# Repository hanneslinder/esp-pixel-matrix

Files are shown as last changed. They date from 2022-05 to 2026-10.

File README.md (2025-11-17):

# ESP-32 Pixel Matrix









## Setup

### web app

- install dependencies with `npm i`
- rename `config.example.ts` file to `config.ts`
- `npm run debug` for local development
- For local development: Update esp32 IP adress in `webpack.config.dev.js`
- `npm run build` to build the project

You should now be able to navigate to `localhost:8080` in your browser. If the ESP32 is already setup and running you should be able to control the matrix now.

### ESP-32

The esp32 code uses [platformIO](https://platformio.org/)

- install dependencies
- wire up the esp
- take contents of `browser/dist` folder and copy into `esp32/data` directory.
- copy data onto esp32 via platformIO `build file system image` and `upload file system image`.

When power is connected, the ESP32 creates a WIFI hotspot and displays the connection settings on the matrix. Connect to this network and use the WIFI portal to configure your WIFI settings. [The credentials for connecting to the portal can be found here](https://github.com/hanneslinder/esp-pixel-matrix/blob/main/esp32/src/main.cpp#L55) The ESP32 then reboots and trys to connect to the configured WIFI. On subsequent reboots, the matrix will show its IP address for 10 seconds before switching to its regular mode.

### OTA updates

Once the matrix is up and running you can update the web app and the ESP32 code via OTA updates.
In the `settings` section of the web interface there is an upload form for OTA update data. This form expects 2 files to be uploaded:
`spiffs.bin` and `firmware.bin`

`spiffs.bin`: contains the web app and can be build via platformIO -> `Build File System Image`
(The web app build process should already copy the built artifacts to the `/esp32/data` directory, which is then used for building the file system image)

`firmware.bin`: contains the esp32 code and can be build via platformIO -> `Build`

The output of both commands sould be located in the `.pio/build/wemos_d1_mini32` folder (`wemos_d1_mini32` might be different if you use another device as build target)

Just upload both files in the web UI. After successful upload the device reboots itself and should have the new code. In theory there should be a rollback mechanism for botched updates included but I've not tried this. So best to not unplug the power while flashing a new firmware :)

Please note that your ESP32 needs the `ota.csv` partition layout!

### pre-build files

In the `bin` directory you can find a pre-build firmware and file system image, suitable for `esp32doit-devkit-v1`. Please note that these files probably won't work with other esp32 boards! If you have another board and cannot build these files yourself, please open an issue and I will add them!

### wire up

This project uses the excellent https://github.com/mrfaptastic/ESP32-HUB75-MatrixPanel-I2S-DMA library. If you are unsure how to connect, there is a nice connection guide there.
In short:

```
  HUB 75 PANEL         ESP 32 PIN
+----------+
|  R1  G1  |    R1  -> IO25    G1 -> IO26
|  B1  GND |    B1  -> IO27
|  R2  G2  |    R2  -> IO14    G2 -> IO12
|  B2  E   |    B2  -> IO13     E -> N/A (required for 1/32 scan panels, like 64x64. Any available pin would do, i.e. IO32 )
|   A  B   |    A   -> IO23     B -> IO19
|   C  D   |    C   -> IO05     D -> IO17
| CLK  LAT |    CLK -> IO16   LAT -> IO 4
|  OE  GND |    OE  -> IO15   GND -> ESP32 GND
+----------+
```

There is also a Gerber file located in the `hardware` folder for a PCB to simplify the connection.

### print the case

You can find `STL` and `STEP` files for the case inside the `hardware` folder.
The case should fit a standard 64x32 pixel p3 led matrix.
I've designed the case to use M3 threaded inserts for all screw holes.
For power I've used a micro usb breakout board like this one: https://www.amazon.de/WayinTop-Breakout-Konverter-Netzteil-Steckbrett/dp/B07W13X3TD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

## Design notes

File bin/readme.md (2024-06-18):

This directory contains pre-build binaries for the `esp32 doit devkit v1` board. (That's what I use for this project)

`firmware.bin` is the esp32 code

`spiffs.bin` contains the file system image that includes the browser based react application

`partitions.bin` contains partition table information

Please be aware that you need to flash all files!

Once you have flashed the files, you should be able to access the captive portal and use it to connect to your wifi.

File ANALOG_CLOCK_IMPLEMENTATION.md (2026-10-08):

# Analog Clock Face Implementation Plan

**Date:** November 17, 2025  
**Status:** Planning Phase - Ready to Implement

## Overview

Implementation of an analog clock face feature for the 64x32 pixel LED matrix display. The clock will be rendered autonomously by the ESP32 and configured via the web UI.

## Design Decisions

### Architecture Pattern

Follows the existing `TextDisplayHandler` pattern:

- **ESP32**: Autonomously renders clock every second using system time
- **Web UI**: Sends configuration once, then provides preview
- **No repeated WebSocket messages** - ESP32 handles all rendering independently

### Feasibility Analysis

A 64x32 pixel display can show a readable analog clock:

- **Clock diameter**: ~28-30 pixels (fits within 32px height)
- **Horizontal centering**: ~17px margins on 64px width
- **Hand design**: Thick hands (2-3px) with different lengths and colors
- **Hour markers**: 12 dots or cardinal points (3, 6, 9, 12)

Similar to classic LCD watch faces that were 20-30 pixels and perfectly readable.

## Implementation Plan

### 1. Add Clock Configuration Types

#### Frontend: `browser/src/state/appState.ts`

```typescript
export interface ClockConfig {
  enabled: boolean;
  centerX: number;          // X position of clock center (0-63)
  centerY: number;          // Y position of clock center (0-31)
  radius: number;           // Clock face radius in pixels
  hourHandColor: string;    // Hex color for hour hand
  minuteHandColor: string;  // Hex color for minute hand
  secondHandColor: string;  // Hex color for second hand
  showSecondHand: boolean;  // Toggle second hand visibility
  hourMarkers: boolean;     // Show hour marker dots
  showBorder: boolean;      // Show clock circle border
  borderColor: string;      // Hex color for border
  hourHandLength: number;   // Length multiplier (0.0-1.0)
  minuteHandLength: number; // Length multiplier (0.0-1.0)
  secondHandLength: number; // Length multiplier (0.0-1.0)
  hourHandWidth: number;    // Hand thickness in pixels
  minuteHandWidth: number;  // Hand thickness in pixels
  secondHandWidth: number;  // Hand thickness in pixels
}

// Add to AppState interface
export interface AppState {
  // ... existing fields ...
  clock: ClockConfig;
}

// Add to getInitialState()
clock: {
  enabled: false,
  centerX: 32,
  centerY: 16,
  radius: 14,
  hourHandColor: "#ffffff",
  minuteHandColor: "#00aaff",
  secondHandColor: "#ff0000",
  showSecondHand: true,
  hourMarkers: true,
  showBorder: true,
  borderColor: "#ffffff",
  hourHandLength: 0.5,
  minuteHandLength: 0.8,
  secondHandLength: 0.9,
  hourHandWidth: 2,
  minuteHandWidth: 2,
  secondHandWidth: 1,
}
```

#### Backend: `esp32/src/types/CommonTypes.h`

```cpp
struct ClockConfig {
  bool enabled;
  int8_t centerX;
  int8_t centerY;
  uint8_t radius;
  uint16_t hourHandColor;     // 565 RGB color
  uint16_t minuteHandColor;   // 565 RGB color
  uint16_t secondHandColor;   // 565 RGB color
  bool showSecondHand;
  bool hourMarkers;
  bool showBorder;
  uint16_t borderColor;
  float hourHandLength;       // 0.0-1.0 multiplier
  float minuteHandLength;     // 0.0-1.0 multiplier
  float secondHandLength;     // 0.0-1.0 multiplier
  uint8_t hourHandWidth;
  uint8_t minuteHandWidth;
  uint8_t secondHandWidth;
};
```

### 2. Create ESP32 ClockDisplayHandler

#### `esp32/src/display/ClockDisplayHandler.h`

```cpp
#ifndef CLOCK_DISPLAY_HANDLER_H
#define CLOCK_DISPLAY_HANDLER_H

#include <Arduino.h>
#include <time.h>
#include "../matrix/MatrixController.h"
#include "../types/CommonTypes.h"

class ClockDisplayHandler {
public:
  ClockDisplayHandler(MatrixController& matrix, ClockConfig* config);

  void renderClock();
  ClockConfig* getConfig();

private:
  void drawClockFace();
  void drawHourMarkers();
  void drawClockHands(int hour, int minute, int second);
  void drawHand(float angle, float length, uint16_t color, uint8_t width);

  MatrixController& _matrix;
  ClockConfig* _config;
  time_t _lastUpdateTime;
};

#endif // CLOCK_DISPLAY_HANDLER_H
```

#### `esp32/src/display/ClockDisplayHandler.cpp`

Key implementation points:

- Get current time using `getLocalTime()`
- Calculate hand angles:
  - Hour: `(hour % 12) * 30 + (minute * 0.5)` degrees
  - Minute: `minute * 6` degrees
  - Second: `second * 6` degrees
- Convert degrees to radians and calculate endpoints
- Use `matrix.drawLine()` for hands
- Use `matrix.drawCircle()` for border
- Use `matrix.fillCircle()` for hour markers
- Only update once per second (check `time_t` change)

### 3. Add WebSocket Handler for Clock Config

#### `esp32/src/websocket/WebSocketHandler.cpp`

Add `handleSetClock()` function:

```cpp
void handleSetClock(JsonDocument& doc) {
  JsonObject clockObj = doc["clock"].as<JsonObject>();

  clockConfig.enabled = clockObj["enabled"];
  clockConfig.centerX = clockObj["centerX"];
  clockConfig.centerY = clockObj["centerY"];
  clockConfig.radius = clockObj["radius"];
  clockConfig.hourHandColor = strtol(clockObj["hourHandColor"], NULL, 16);
  clockConfig.minuteHandColor = strtol(clockObj["minuteHandColor"], NULL, 16);
  clockConfig.secondHandColor = strtol(clockObj["secondHandColor"], NULL, 16);
  clockConfig.showSecondHand = clockObj["showSecondHand"];
  clockConfig.hourMarkers = clockObj["hourMarkers"];
  clockConfig.showBorder = clockObj["showBorder"];
  clockConfig.borderColor = strtol(clockObj["borderColor"], NULL, 16);
  clockConfig.hourHandLength = clockObj["hourHandLength"];
  clockConfig.minuteHandLength = clockObj["minuteHandLength"];
  clockConfig.secondHandLength = clockObj["secondHandLength"];
  clockConfig.hourHandWidth = clockObj["hourHandWidth"];
  clockConfig.minuteHandWidth = clockObj["minuteHandWidth"];
  clockConfig.secondHandWidth = clockObj["secondHandWidth"];
}
```

Register in `handleMessage()`:

```cpp
} else if (isStringEqual(action, "setClock")) {
  handleSetClock(doc);
}
```

### 4. Integrate Clock Rendering in Main Loop

#### `esp32/src/main.cpp`

```cpp
// Add global
ClockConfig clockConfig = {
  .enabled = false,
  .centerX = 32,
  .centerY = 16,
  .radius = 14,
  // ... other defaults
};

// Initialize in setup()
ClockDisplayHandler clockDisplay(matrix, &clockConfig);

// In loop(), add after text rendering:
} else if (clockConfig.enabled) {
  clockDisplay.renderClock();
}
```

### 5. Create Browser Canvas Clock Preview Layer

#### `browser/src/components/canvas/CanvasClockLayer.ts`

```typescript
import { observe } from "@nx-js/observer-util";
import { appState } from "../../state/appState";

export class CanvasClockLayer {
  private ctx: CanvasRenderingContext2D;
  private canvas: HTMLCanvasElement;
  private updateInterval: any;

  constructor(container: HTMLElement) {
    this.canvas = document.createElement("canvas");
    this.canvas.setAttribute("id", "canvas-clock-layer");
    this.ctx = this.canvas.getContext("2d");

    this.canvas.width = appState.settings.width * appState.settings.pixelRatio;
    this.canvas.height =
      appState.settings.height * appState.settings.pixelRatio;

    container.appendChild(this.canvas);
    this.observeChanges();
  }

  private observeChanges() {
    observe(() => {
      if (appState.clock.enabled) {
        this.startClock();
      } else {
        this.stopClock();
      }
    });
  }

  private startClock() {
    clearInterval(this.updateInterval);
    this.updateInterval = setInterval(() => this.renderClock(), 1000);
    this.renderClock(); // Immediate render
  }

  private stopClock() {
    clearInterval(this.updateInterval);
    this.reset();
  }

  private renderClock() {
    const config = appState.clock;
    const ratio = appState.settings.pixelRatio;
    const now = new Date();

    this.reset();

    if (!config.enabled) return;

    const centerX = config.centerX * ratio;
    const centerY = config.centerY * ratio;
    const radius = config.radius * ratio;

    // Draw border
    if (config.showBorder) {
      this.ctx.strokeStyle = config.borderColor;
      this.ctx.lineWidth = ratio;
      this.ctx.beginPath();
      this.ctx.arc(centerX, centerY, radius, 0, 2 * Math.PI);
      this.ctx.stroke();
    }

    // Draw hour markers
    if (config.hourMarkers) {
      for (let i = 0; i < 12; i++) {
        const angle = ((i * 30 - 90) * Math.PI) / 180;
        const markerRadius = radius * 0.85;
        const x = centerX + Math.cos(angle) * markerRadius;
        const y = centerY + Math.sin(angle) * markerRadius;

        this.ctx.fillStyle = config.borderColor;
        this.ctx.beginPath();
        this.ctx.arc(x, y, ratio, 0, 2 * Math.PI);
        this.ctx.fill();
      }
    }

    // Calculate angles
    const hours = now.getHours() % 12;
    const minutes = now.getMinutes();
    const seconds = now.getSeconds();

    const hourAngle = ((hours * 30 + minutes * 0.5 - 90) * Math.PI) / 180;
    const minuteAngle = ((minutes * 6 - 90) * Math.PI) / 180;
    const secondAngle = ((seconds * 6 - 90) * Math.PI) / 180;

    // Draw hands
    this.drawHand(
      centerX,
      centerY,
      hourAngle,
      radius * config.hourHandLength,
      config.hourHandColor,
      config.hourHandWidth * ratio
    );
    this.drawHand(
      centerX,
      centerY,
      minuteAngle,
      radius * config.minuteHandLength,
      config.minuteHandColor,
      config.minuteHandWidth * ratio
    );
    if (config.showSecondHand) {
      this.drawHand(
        centerX,
        centerY,
        secondAngle,
        radius * config.secondHandLength,
        config.secondHandColor,
        config.secondHandWidth * ratio
      );
    }
  }

  private drawHand(
    cx: number,
    cy: number,
    angle: number,
    length: number,
    color: string,
    width: number
  ) {
    this.ctx.strokeStyle = color;
    this.ctx.lineWidth = width;
    this.ctx.lineCap = "round";
    this.ctx.beginPath();
    this.ctx.moveTo(cx, cy);
    this.ctx.lineTo(
      cx + Math.cos(angle) * length,
      cy + Math.sin(angle) * length
    );
    this.ctx.stroke();
  }

  private reset() {
    this.ctx.clearRect(0, 0, this.canvas.width, this.canvas.height);
  }

  public destroy() {
    clearInterval(this.updateInterval);
    this.canvas.remove();
  }
}
```

### 6. Create Clock View Component

#### `browser/src/components/views/clock/ClockView.tsx`

UI controls needed:

- Toggle clock enabled
- Color pickers for each hand and border
- Sliders for position (centerX, centerY)
- Slider for radius
- Sliders for hand lengths
- Sliders for hand widths
- Toggles for second hand, hour markers, border

### 7. Add Clock Action and Integration

#### `browser/src/Actions.ts`

```typescript
export const setClockAction = () => {
  const clockToSend = {
    ...appState.clock,
    hourHandColor: convertHexTo16Bit(appState.clock.hourHandColor),
    minuteHandColor: convertHexTo16Bit(appState.clock.minuteHandColor),
    secondHandColor: convertHexTo16Bit(appState.clock.secondHandColor),
    borderColor: convertHexTo16Bit(appState.clock.borderColor),
  };

  const msg = {
    action: "setClock",
    clock: clockToSend,
  };

  socket.send(msg);
};
```

#### `browser/src/components/Navigation.tsx`

Add Clock to Views enum and navigation items

#### `browser/src/components/canvas/CanvasWrapper.tsx`

Instantiate CanvasClockLayer alongside other layers

## Technical Notes

### Math for Clock Hands

```
Hour Hand Angle = (hours % 12) * 30 + (minutes * 0.5) - 90 degrees
Minute Hand Angle = minutes * 6 - 90 degrees
Second Hand Angle = seconds * 6 - 90 degrees

// Convert to radians and calculate endpoint:
x = centerX + cos(angle * PI / 180) * length
y = centerY + sin(angle * PI / 180) * length
```

### ESP32 Drawing Functions Available

- `matrix->drawLine(x0, y0, x1, y1, color)`
- `matrix->drawCircle(x, y, radius, color)`
- `matrix->fillCircle(x, y, radius, color)`
- `matrix->drawPixel(x, y, color)`

### Performance Considerations

- ESP32 should only redraw when second changes (check `time_t`)
- Browser can update every second with `setInterval`
- Use separate layer to avoid redrawing background
- Consider clearing only clock layer, not entire display

## Testing Checklist

- [ ] Clock configuration saves/loads properly
- [ ] Clock hands move correctly (test at different times)
- [ ] Browser preview matches ESP32 display
- [ ] Second hand toggle works
- [ ] Hour markers toggle works
- [ ] All color pickers work
- [ ] Clock can be positioned anywhere on display
- [ ] Clock resizes correctly with radius slider
- [ ] Hand lengths and widths adjust properly
- [ ] Clock disables properly when toggled off
- [ ] Clock works with different composition modes
- [ ] Clock coexists with text/background layers

## Future Enhancements (Optional)

- Multiple clock face styles (Roman numerals, digital hybrid, etc.)
- Date display inside/below clock
- Timezone selection per clock
- Multiple clocks showing different timezones
- Smooth second hand motion (interpolation)
- Custom color schemes / presets
- Day/night mode auto-brightness

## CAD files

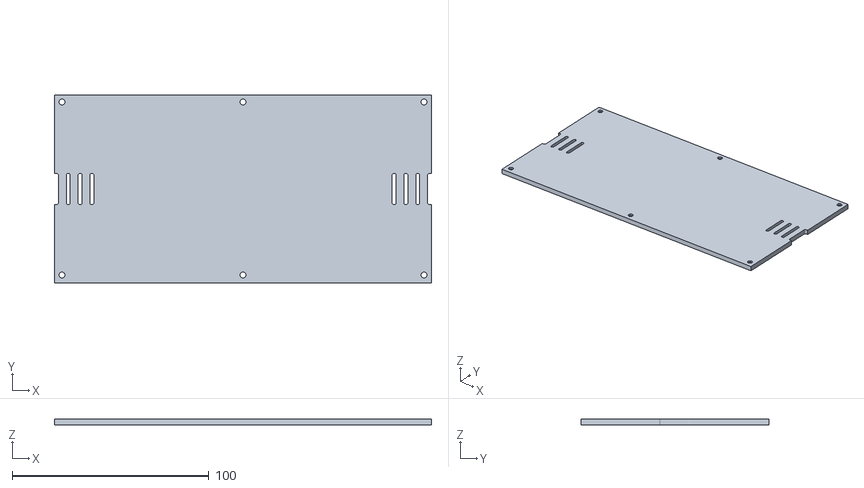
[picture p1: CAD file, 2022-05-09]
hardware/matrix-case-back.stl
191.6 x 95.6 x 3.00

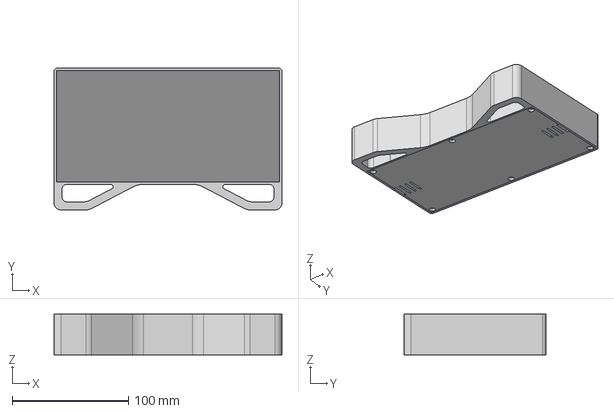
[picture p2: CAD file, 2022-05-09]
hardware/matrix-case.step
196.0 x 122.0 x 35.0 mm

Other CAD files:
hardware/matrix-case.stl

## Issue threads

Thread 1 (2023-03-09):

Please consider uploading the PCB schematics

manutenfruits, 2023-03-09:
Hi, I got your pcb fabricated but I'm missing some information like schematics, and what component goes in the small square (I'm guessing a photoresistor?).

I know I can reverse engineer it but would be great if we had access to the original schematic, or even better, the whole kicad project (if you used that!).

Thanks!

hanneslinder, 2023-05-09:
Sorry for the late reply, completely missed your comment.
Regarding the schematic, I created it with [EasyEDA](https://easyeda.com/), so there is no kicad file I can share.

Now that you point it out I never specified what the additional through holes are for 🙈
The larger one is for providing power and the smaller one is for a push button that resets the clock when pressed for 5 seconds.

I've attached a picture of the backside of the clock, hope that clears it up a bit
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

Let me know if you have any more questions.
Cheers!

Closed 2023-09-12.

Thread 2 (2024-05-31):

Informations ?

spordiab, 2024-05-31:
Thank you for your project, however I don't have much programming knowledge, I use Arduino IDE and I have the same ESP32 board with the same Matrix screen.  I wanted to know if you could generate a.bin file to flash directly with ESPHome Flasher, it would be easier for beginners.  Thank you so much

hanneslinder, 2024-06-17:
Thanks for the suggestion and sorry for my late reply.
A `.bin` file sounds like an interesting addition to help getting started with the project faster. I'll look into it and add it to the project as soon as I find the time 👍

hanneslinder, 2024-06-17:
@spordiab I've added pre-build files for the `esp32doit-devkit-v1` board in the `/bin` directory. Please note that you also need to flash both files!
Let me know if this works for you.

cheers!

spordiab, 2024-06-17:
OMG, Thanks 😊

Closed 2024-06-17.

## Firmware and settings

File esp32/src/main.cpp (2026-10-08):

#include "SPIFFS.h"
#include "time.h"
#include <Arduino.h>
#include <ArduinoJson.h>
#include <AsyncTCP.h>
#include <ESP32-HUB75-MatrixPanel-I2S-DMA.h>
#include <ESPAsyncWebServer.h>
#include <ESPmDNS.h>
#include <Fonts/Picopixel.h>
#include <GFX_Layer.hpp>
#include <HTTPClient.h>
#include <MycilaESPConnect.h>
#include <Update.h>
#include <WiFi.h>
#include <Wire.h>
#include <sstream>

#include "config/ConfigManager.h"
#include "config/pins.h"
#include "config/secrets.h"
#include "config/settings.h"
#include "data/CustomDataHandler.h"
#include "display/TextDisplayHandler.h"
#include "input/ResetButtonHandler.h"
#include "matrix/MatrixController.h"
#include "ota/OTAUpdateHandler.h"
#include "quiet/QuietHoursHandler.h"
#include "server/WebServerHandler.h"
#include "types/CommonTypes.h"
#include "utils/utils.h"
#include "websocket/WebSocketHandler.h"
#include "wifi/WiFiConnectionHandler.h"

#define U_PART U_SPIFFS

// Get singleton instance of ConfigManager
ConfigManager& config = ConfigManager::getInstance();

// Moved OTA progress state into OTAUpdate module

MatrixController matrix;

bool startupFinished = false;

// clock options - to be migrated to state manager
boolean showText = true;
boolean lastshowText = false;
boolean forceUpdateTime = false;

// Mutable copies for runtime configuration
char currentTimezone[64];

TextItem textContent[5]
    = { { "%H:%M", 0xFFFF, -1, -5, 1, 2, 1 }, { "%d.%b", 0xFFFF, 2, -3, 1, 1, 2 } };

char* socketData;
int currSocketBufferIndex = 0;

// custom data - kept for WebSocketHandler access
int customDataUpdateInterval = -1;
boolean customDataEnabled = false;
char customDataServer[128] = "";

static unsigned long lastHeapCheck = 0;
static size_t minFreeHeap = SIZE_MAX;

// Initialize handlers and server
AsyncWebServer server(80);
AsyncWebSocket ws("/ws");
WiFiConnectionHandler wifiHandler(server);
ResetButtonHandler resetButton(RESET_PIN, RESET_SHORT_PRESS_TIME);
TextDisplayHandler textDisplay(matrix, textContent, 5);
QuietHoursHandler quietHours(matrix);
WebServerHandler webServer(server, ws);
CustomDataHandler customData;

void initMatrix() { matrix.begin(); }

void onEvent(AsyncWebSocket* server, AsyncWebSocketClient* client, AwsEventType type, void* arg,
    uint8_t* data, size_t len)
{
  switch (type) {
  case WS_EVT_CONNECT:
    WebSocketHandler::onConnect(client);
    break;
  case WS_EVT_DISCONNECT:
    WebSocketHandler::onDisconnect(client);
    break;
  case WS_EVT_DATA:
    WebSocketHandler::handleMessage(arg, data, len);
    break;
  case WS_EVT_PONG:
    break;
  case WS_EVT_ERROR:
    WebSocketHandler::onError(client);
    break;
  }
}

void resetWifi() { wifiHandler.reset(); }

void initWebSocket()
{
  ws.onEvent(onEvent);
  server.addHandler(&ws);
  ws.enable(true);

  WebSocketHandler::init(&matrix, textContent, &ws, socketData, &currSocketBufferIndex,
      SOCKET_DATA_SIZE, &textDisplay, &customData, &quietHours);
}

void checkHeapAndLog()
{
  size_t freeHeap = ESP.getFreeHeap();
  size_t heapSize = ESP.getHeapSize();
  size_t minHeap = ESP.getMinFreeHeap();

  if (freeHeap < minFreeHeap) {
    minFreeHeap = freeHeap;
  }

  Serial.println("=== System Status ===");
  Serial.printf("Free Heap: %u bytes (%.1f%%)\n", freeHeap, (freeHeap * 100.0) / heapSize);
  Serial.printf("Min Free Heap: %u bytes\n", minHeap);
  Serial.printf("Heap Size: %u bytes\n", heapSize);
  Serial.printf("WiFi Status: %s (RSSI: %d dBm)\n",
      wifiHandler.isConnected() ? "Connected" : "Disconnected", wifiHandler.getRSSI());
  Serial.printf("WebSocket Clients: %u\n", ws.count());
  Serial.printf("Uptime: %lu seconds\n", millis() / 1000);
  Serial.println("====================");

  // Warning if heap is getting low
  if (freeHeap < 30000) {
    Serial.println("WARNING: Low heap memory! System may become unstable.");
  }
}

void setup()
{
  Serial.begin(115200);
  SPIFFS.begin();

  // Initialize ConfigManager first
  config.begin();

  // Initialize text display with locale from config
  textDisplay.setLocale(config.getLocale());

  socketData = (char*)malloc(SOCKET_DATA_SIZE * sizeof(char));

  // Initialize reset button
  resetButton.begin();
  resetButton.onLongPress([]() { resetWifi(); });

  // Copy timezone from config for runtime use
  strlcpy(currentTimezone, config.getTimezone(), sizeof(currentTimezone));

  // Initialize WiFi
  wifiHandler.begin(useCaptivePortal, ssid, password);

  // Initialize matrix
  initMatrix();

  // Apply brightness from config
  matrix.setBrightness(config.getBrightness());
  Serial.printf("Set initial brightness to %d\n", config.getBrightness());

  // Quiet hours need the matrix ready before they can take over the screen
  quietHours.begin();

  // Initialize WebSocket and Web Server
  initWebSocket();
  webServer.begin();

  // Configure timezone and NTP
  configTzTime(config.getTimezone(), config.getNtpServer());
  Serial.printf("Configured NTP: %s, Timezone: %s\n", config.getNtpServer(), config.getTimezone());
}

void loop()
{
  wifiHandler.loop();
  resetButton.update();

  if (startupFinished == false) {
    const String ip = wifiHandler.getIPAddress();

    matrix.drawText(ip.c_str(), MIDDLE, &Picopixel, 0xFFFF, 1, 0, 0, 1);
    matrix.render(config.getCompositionMode());

    delay(6000);

    startupFinished = true;
  } else if (resetButton.isPressed()) {
    char resetTimeString[16];
    itoa(resetButton.getPressDuration(), resetTimeString, 10);
    matrix.getTextLayer().clear();
    matrix.getTextLayer().setCursor(0, 0);
    matrix.getTextLayer().println("Reset");
    matrix.getTextLayer().setCursor(0, 16);
    matrix.getTextLayer().println(resetTimeString);
  } else if (showText == true) {
    textDisplay.renderText();
  }

  customData.update();

  ws.cleanupClients();

  // Quiet hours take over the screen when they are active, so this decides
  // what the panel shows before the frame is pushed out.
  quietHours.update();

  matrix.render(config.getCompositionMode(), quietHours.isActive());

  if (millis() - lastHeapCheck > 300000) {
    lastHeapCheck = millis();
    checkHeapAndLog();
  }

  wifiHandler.checkConnection();

  delay(100);
}

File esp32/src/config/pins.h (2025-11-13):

#pragma once

// Matrix Panel Pins
#define USE_CUSTOM_PINS
#define A_PIN 5
#define B_PIN 19
#define C_PIN 22
#define D_PIN 21
#define E_PIN 12

#define R1_PIN 2
#define R2_PIN 18
#define G1_PIN 15
#define G2_PIN 27
#define B1_PIN 4
#define B2_PIN 14

#define CLK_PIN 23
#define LAT_PIN 25
#define OE_PIN 26

#define RESET_PIN 32

// Matrix Configuration
#define PANEL_WIDTH 64
#define PANEL_HEIGHT 32
#define PANEL_CHAIN 1

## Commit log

2022-05-09 open source repo
    [matrix-case-back.stl, matrix-case.step, matrix-case.stl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]
2022-05-10 Fix syncing of empty text lines
    [main.cpp]
2022-05-16 Fix text restore bug. Introduct experimental new text renderer.
    [main.cpp]
2022-05-17 Increase SPIFFS partition size
    [ota.csv]
2023-12-27 Fix wifi sleep and add formatter
    [main.cpp]
2024-06-17 Add pre-build files for `esp32doit-devkit-v1`
2025-11-12 Trying to fix memory leaks
    [main.cpp]
2025-11-12 extract ota handling and fix oom error for some images
    [OTAUpdateHandler.cpp, main.cpp]
2025-11-12 refactor socket handler
2025-11-13 print ip address on startup
2025-11-13 move reset handling into separate file
    [main.cpp]
2025-11-13 Refactor frontend and replace react with preact
    [WebServerHandler.cpp]
2025-11-17 Fix initial text centering
    [main.cpp]
2025-11-17 Align text position with esp32 rendering
